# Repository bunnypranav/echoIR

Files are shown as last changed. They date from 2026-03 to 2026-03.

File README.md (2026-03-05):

# EchoIR


This is an IR hub, with both an IR receiver and a handful of transmitters, which can control my IR appliances, like the AC, fan, and TV, with my phone and over the internet. It wouldn't replace the remotes, but it could learn their signals and replay them whenever I want from my phone.

# Schematic
*Made in KiCad*

On the left side is the USB-C connector, going into the polyfuse, then into the +5V rail. The three IR LEDs each have their own 33-ohm resistor and connect from +5V to the IRLEDNODE. When the MOSFET turns on, current flows through all three LEDs to ground. The TSOP38238 receiver runs from +3.3V, which comes from the Pico's internal regulator. There is a 100nF capacitor and a 4.7uF capacitor close to it, because IR receivers are sensitive to noise. The button connected to GPIO 14 controls the "record" mode, with its status led just being the inbuilt Pi led at GPIO25.

page_1

# PCB
*Made in KiCad*
pcb
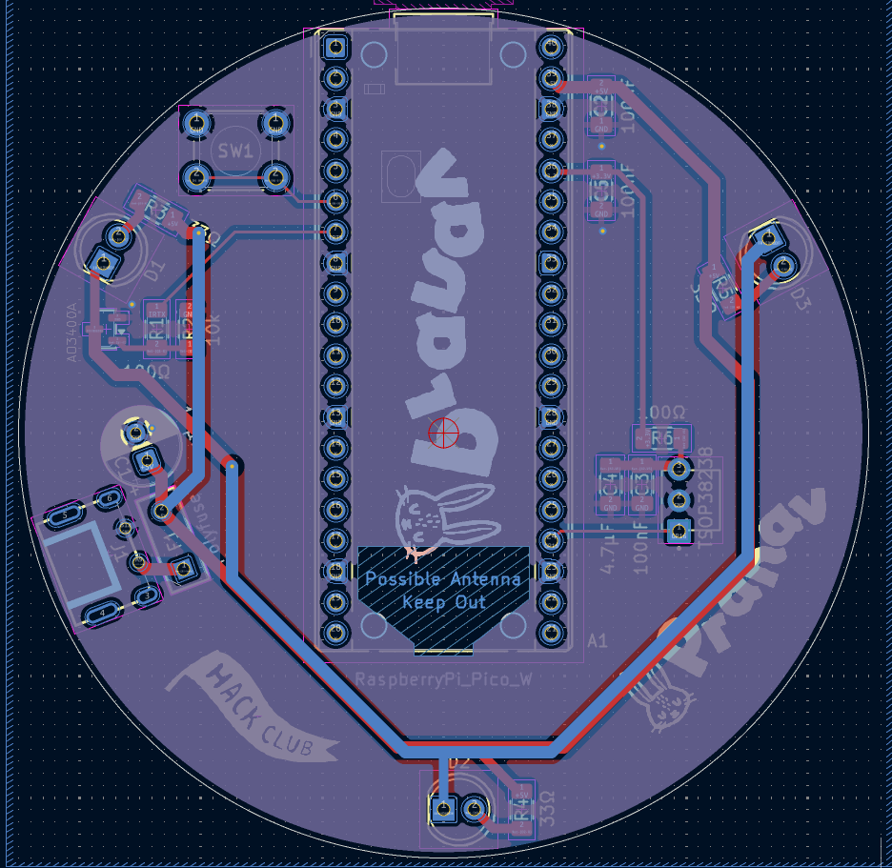
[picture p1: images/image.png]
pcb2


# Firmware
*Written in CircuitPython*

The Pico 2W connects to WiFi on boot and starts a HTTP server that exposes a simple webhook endpoint. When I press the button, it enters a short recording window and captures the raw pulse timings from the TSOP38238, then stores them in memory with an incrementing ID number. The IR LEDs are driven from GPIO5 using a 38kHz PWM carrier, and when a POST request is sent to `/play` with a JSON body like `{"id": 3}`, the Pico looks up that stored signal and replays it through the three IR transmitters. Everything runs locally on the Pico, so another computer on the same network can trigger appliances just by sending a simple HTTP request. This can also be easily plugged in to home automation services, or be modified to worth with MQTT, something I plan to do in the future.

# CAD Base
*Designed in Fusion 360*

Created a basic CAD base for the PCB to sit on. I did not create any top cover, since the LEDs cannot shine through solid PLA plastic, neither can the TSOP recieve IR pulses. This is just to prevent the bottom pins from scratching the surface I put this on.



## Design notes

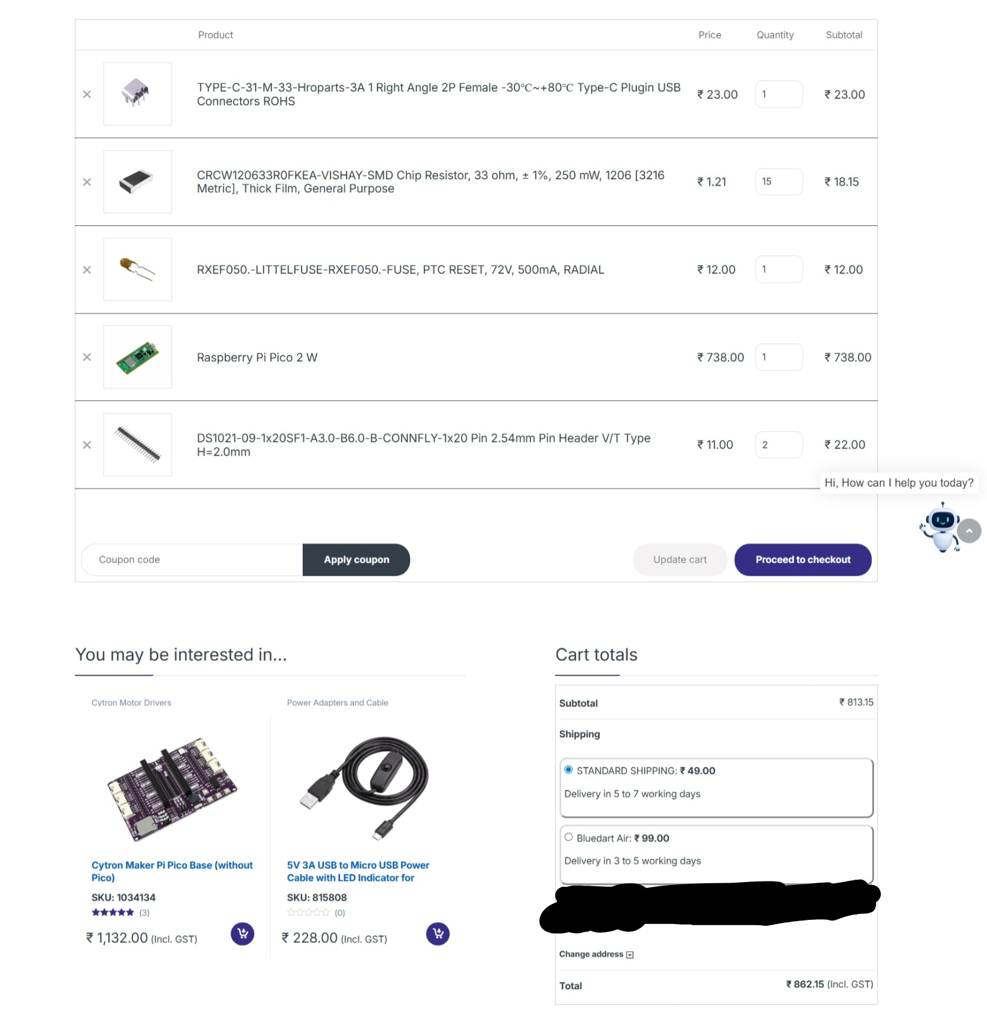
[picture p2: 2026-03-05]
CartScreenshots/Robu.png

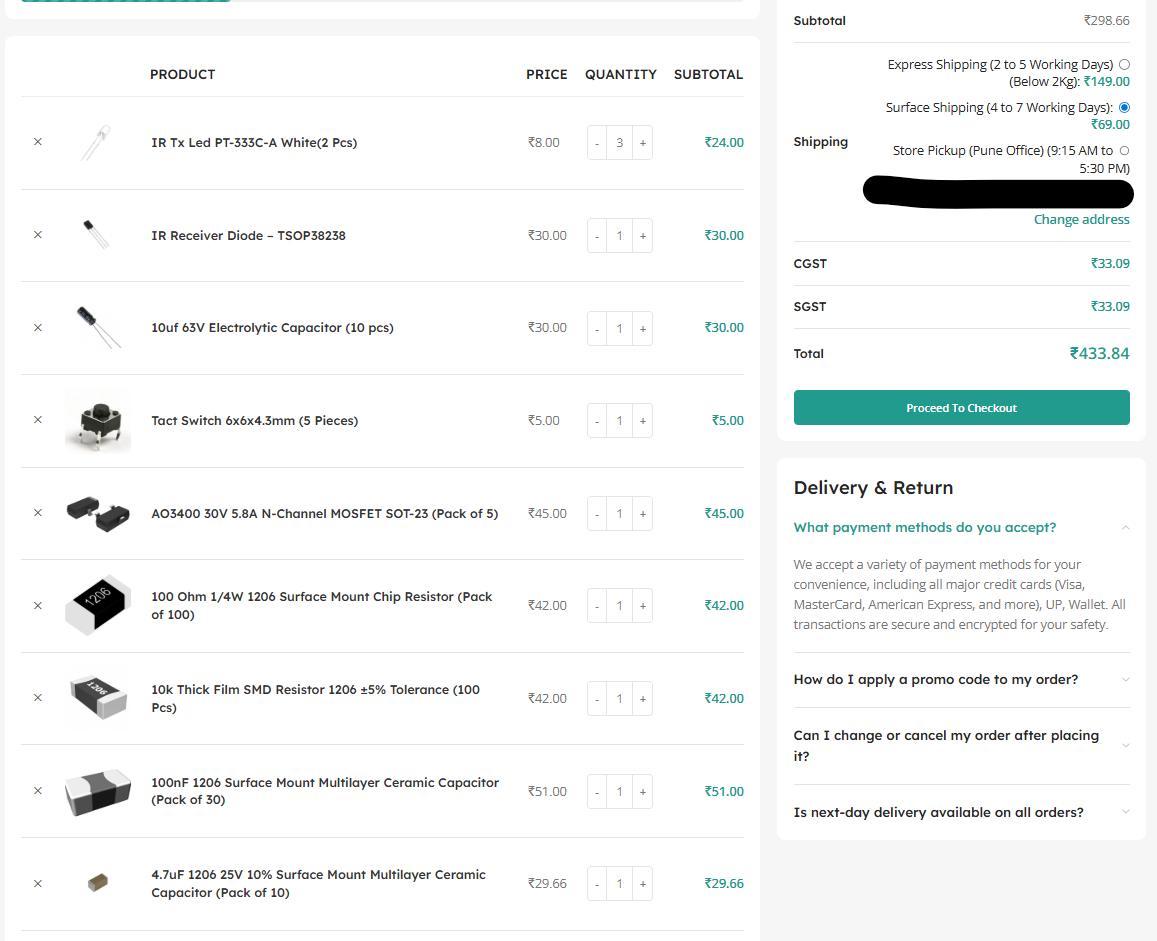
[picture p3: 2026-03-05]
CartScreenshots/robodna.png

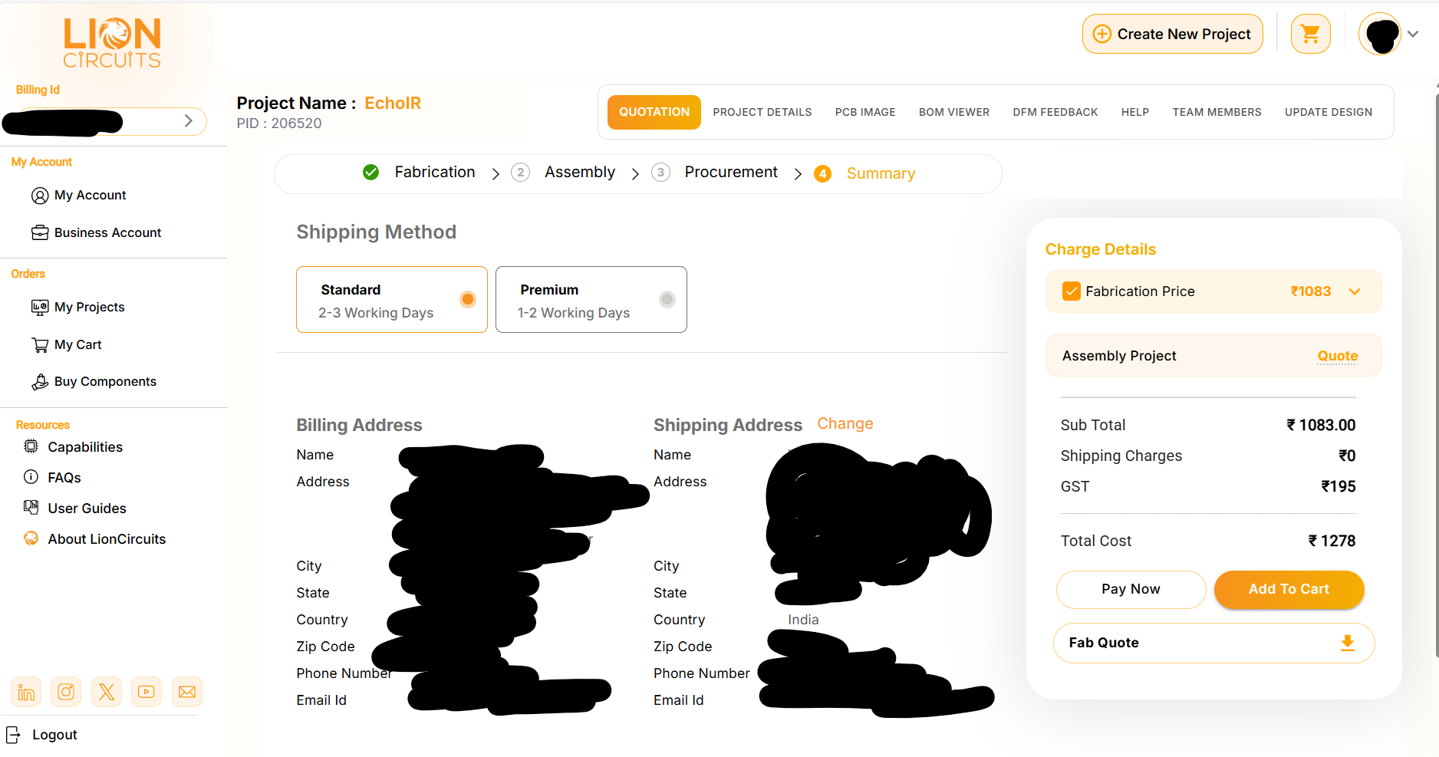
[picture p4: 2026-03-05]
CartScreenshots/PCB.png

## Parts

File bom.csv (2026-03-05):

Name | Purpose | Cost (USD) | Qty | Total (USD) | Link | Distributor
Printing legion shipping | Shipping cost for the 3D printed base from printing legion; domestic shipping within India | $3.00 | 1 | $3.00 | - | Shiprocket
33-ohm 1206 Resistor | LED resistor; 15 cause SMD is hard and I'm a beginner at soldering | $0.02 | 15 | $0.24 | https://robu.in/product/crcw120633r0fkea-vishay-smd-chip-resistor-33-ohm-%c2%b1-1-250-mw-1206-3216-metric-thick-film-general-purpose/ | Robu
LionCircuits PCB Fabrication | PCB Fabrication | $14.06 | 1 | $14.06 | https://lioncircuits.com/ | LionCircuits
RoboticsDNA Shipping | Standard cheapest shipping cost | $0.76 | 1 | $0.76 | - | RoboticsDNA
Robu Shipping | Standard cheapest shipping cost | $0.55 | 1 | $0.55 | - | Robu
Tactile Switch 6mm | Controlling mode | $0.07 | 1 | $0.07 | https://roboticsdna.in/product/tact-switch-2-pieces/ | RoboticsDNA
10k 1206 Resistor | MOSFET resistor | $0.55 | 1 | $0.55 | https://roboticsdna.in/product/10k%cf%89-thick-film-smd-resistor-1206-%c2%b15-tolerence-100-pcs/ | RoboticsDNA
100-ohm 1206 Resistor | LED power resistor | $0.55 | 1 | $0.55 | https://roboticsdna.in/product/100-ohm-1-4w-1206-surface-mount-chip-resistor-pack-of-100/ | RoboticsDNA
AO3400A | MOSFET | $0.59 | 1 | $0.59 | https://roboticsdna.in/product/ao3400-30v-5-8a-n-channel-mosfet-sot-23-pack-of-5/ | RoboticsDNA
USB C receptacle 31-M-33 | USB power | $0.26 | 1 | $0.26 | https://robu.in/product/type-c-31-m-33-hroparts-3a-1-right-angle-2p-female-30%e2%84%8380%e2%84%83-type-c-plugin-usb-connectors-rohs/ | Robu
RXEF050 Polyfuse | Fuse | $0.13 | 1 | $0.13 | https://robu.in/product/rxef050-littelfuse-rxef050-fuse-ptc-reset-72v-500ma-radial/ | Robu
IR Tx Led PT-333C-A | IR Transmission | $0.10 | 3 | $0.30 | https://roboticsdna.in/product/ir-tx-led-pt-333c-a-white2-pcs/ | RoboticsDNA
10uF radial Capacitor | Decoupling | $0.39 | 1 | $0.39 | https://roboticsdna.in/product/10uf-63v-capacitor-5-pieces/ | RoboticsDNA
TSOP38238 | IR reciever for training MCU | $0.39 | 1 | $0.39 | https://roboticsdna.in/product/ir-receiver-diode-tsop38238/ | RoboticsDNA
4.7uF 1206 Capacitor | Decoupling | $0.39 | 1 | $0.39 | https://roboticsdna.in/product/4-7uf-1206-surface-mount-multilayer-ceramic-capacitor-pack-of-30/ | RoboticsDNA
100nF 1206 Capacitor | Decoupling | $0.66 | 1 | $0.66 | https://roboticsdna.in/product/100nf-1206-surface-mount-multilayer-ceramic-capacitor-pack-of-30/ | RoboticsDNA
1x20 headers for Pico | THT mounting Pi, I am beginner at soldering | $0.12 | 2 | $0.24 | https://robu.in/product/ds1021-09-1x20sf1-a3-0-b6-0-b-connfly-1x20-pin-2-54mm-pin-header-v-t-type-h2-0mm/ | Robu
RaspberryPi Pico 2 W | Main MCU and Wifi connectivity | $8.12 | 1 | $8.12 | https://robu.in/product/raspberry-pi-pico-2-w/ | Robu

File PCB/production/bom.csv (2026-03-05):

Designator | Footprint | Quantity | Value | LCSC Part #
A1 | RaspberryPi_Pico_Common_THT | 1 | RaspberryPi_Pico_W
A2 | XDCR_TSOP38238 | 1 | TSOP38238
C1 | CP_Radial_D6.3mm_P2.50mm | 1 | 10µF
C2, C3, C5 | 1206 | 3 | 100nF
C4 | 1206 | 1 | 4.7µF
D1, D2, D3 | LED_D5.0mm | 3 | LED
F1 | FUS_RXEF050_TYCO_TYC | 1 | Polyfuse
J1 | USB-C-TH_TYPE-C-31-M-33 | 1 | USB_C_Receptacle_PowerOnly_6P
Q1 | SOT-23 | 1 | AO3400A
R1, R6 | 1206 | 2 | 100Ω
R2 | 1206 | 1 | 10k
R3, R4, R5 | 1206 | 3 | 33Ω
SW1 | SW_PUSH_6mm | 1 | SW_Push

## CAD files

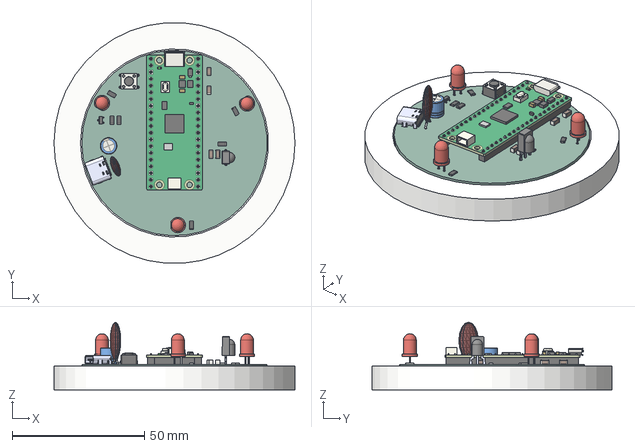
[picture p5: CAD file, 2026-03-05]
CAD/echoIR_fullProject.step
91.0 x 90.7 x 25.6 mm

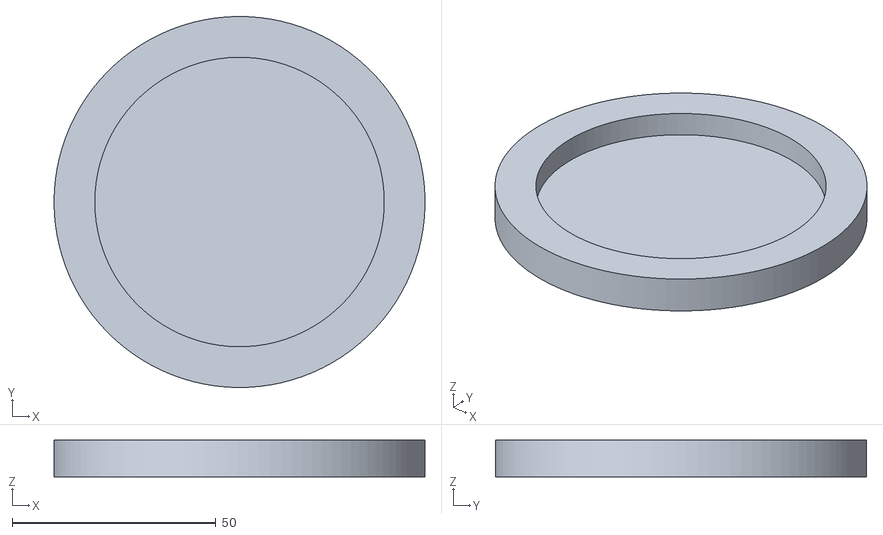
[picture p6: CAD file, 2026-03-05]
CAD/Base.stl
91.0 x 91.0 x 9.00

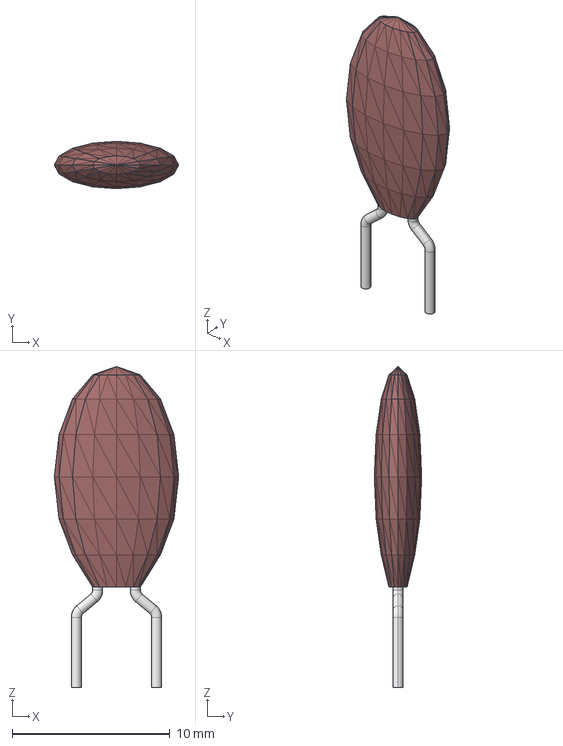
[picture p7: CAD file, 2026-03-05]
PCB/SymbolFootprints/RXEF050/FUS_RXEF050_TYCO_TYC.step
7.87 x 3.00 x 20.3 mm

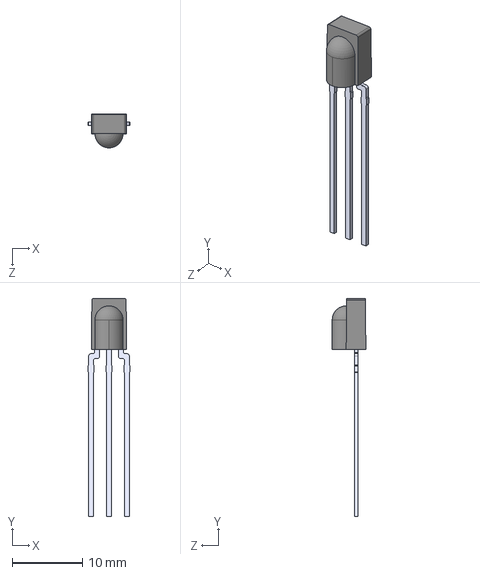
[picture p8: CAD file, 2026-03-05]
PCB/SymbolFootprints/TSOP38238/TSOP38238.STEP
5.93 x 31.0 x 4.80 mm

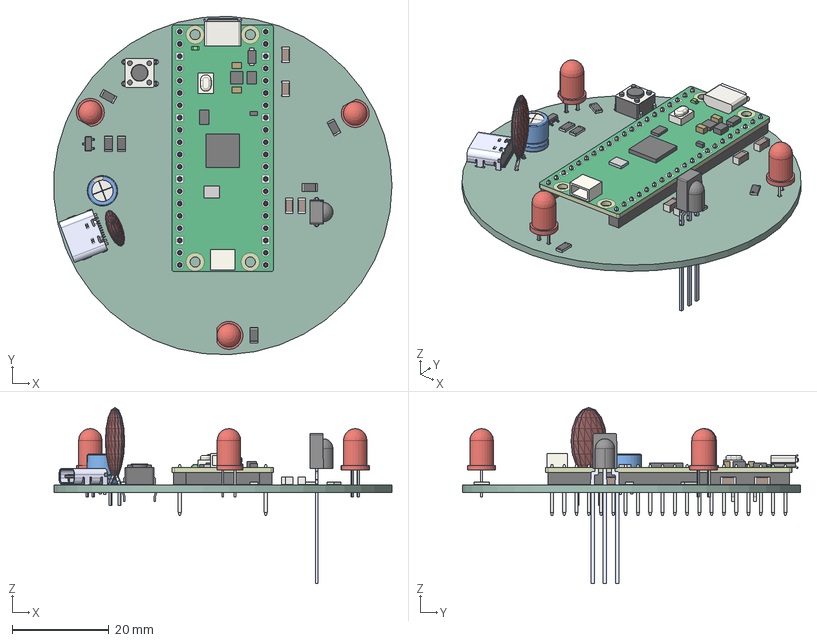
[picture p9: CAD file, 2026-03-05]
CAD/PCB.step
69.9 x 69.9 x 36.4 mm
LED_D5.0mm x 3
C_1206_3216Metric x 4
R_1206_3216Metric x 6
SOT-23
TYPE-C-31-M-12
TSOP38238
RaspberryPi_Pico_H_Module_KiCad
RaspberryPi_Pico_Header_DIP-40_H2.54mm_KiCad
CP_Radial_D6.3mm_P2.50mm
SW_PUSH_6mm
FUS_RXEF050_TYCO_TYC
echoIR_PCB

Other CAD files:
CAD/echoIR_fullProject.f3z

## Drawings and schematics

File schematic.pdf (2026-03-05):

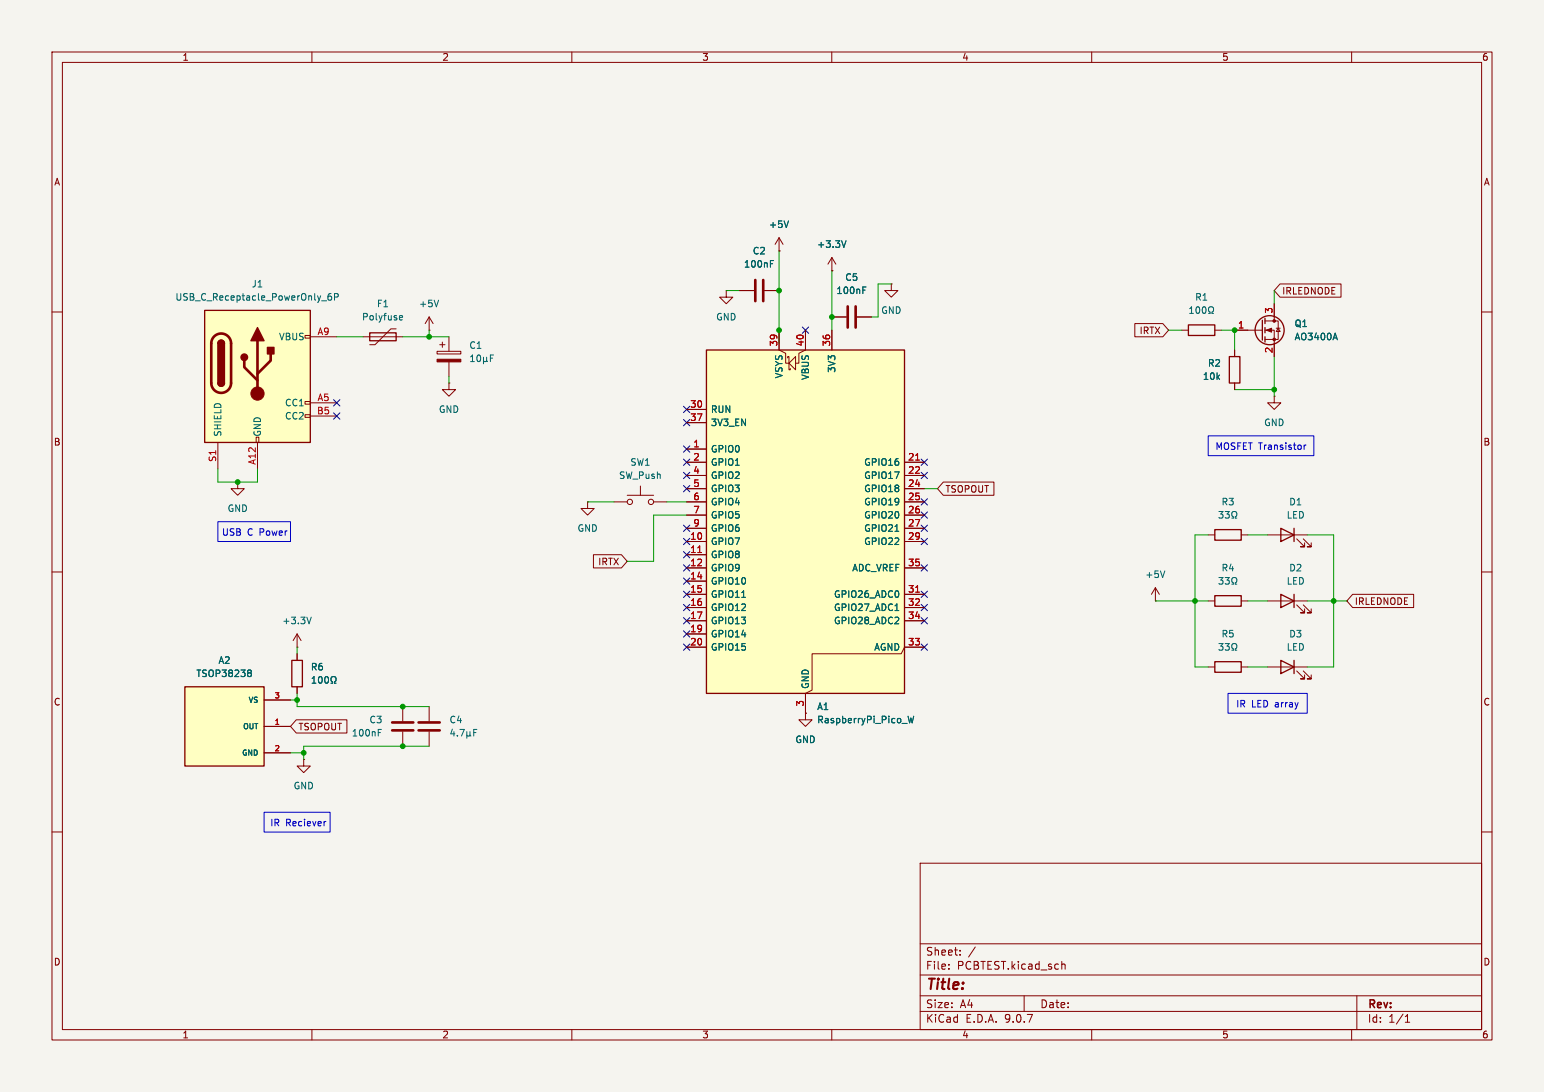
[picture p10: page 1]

IR LED array MOSFET Transistor A2 TSOP38238

Id: 1/1 Title: File: PCBTEST.kicad_sch Sheet: /

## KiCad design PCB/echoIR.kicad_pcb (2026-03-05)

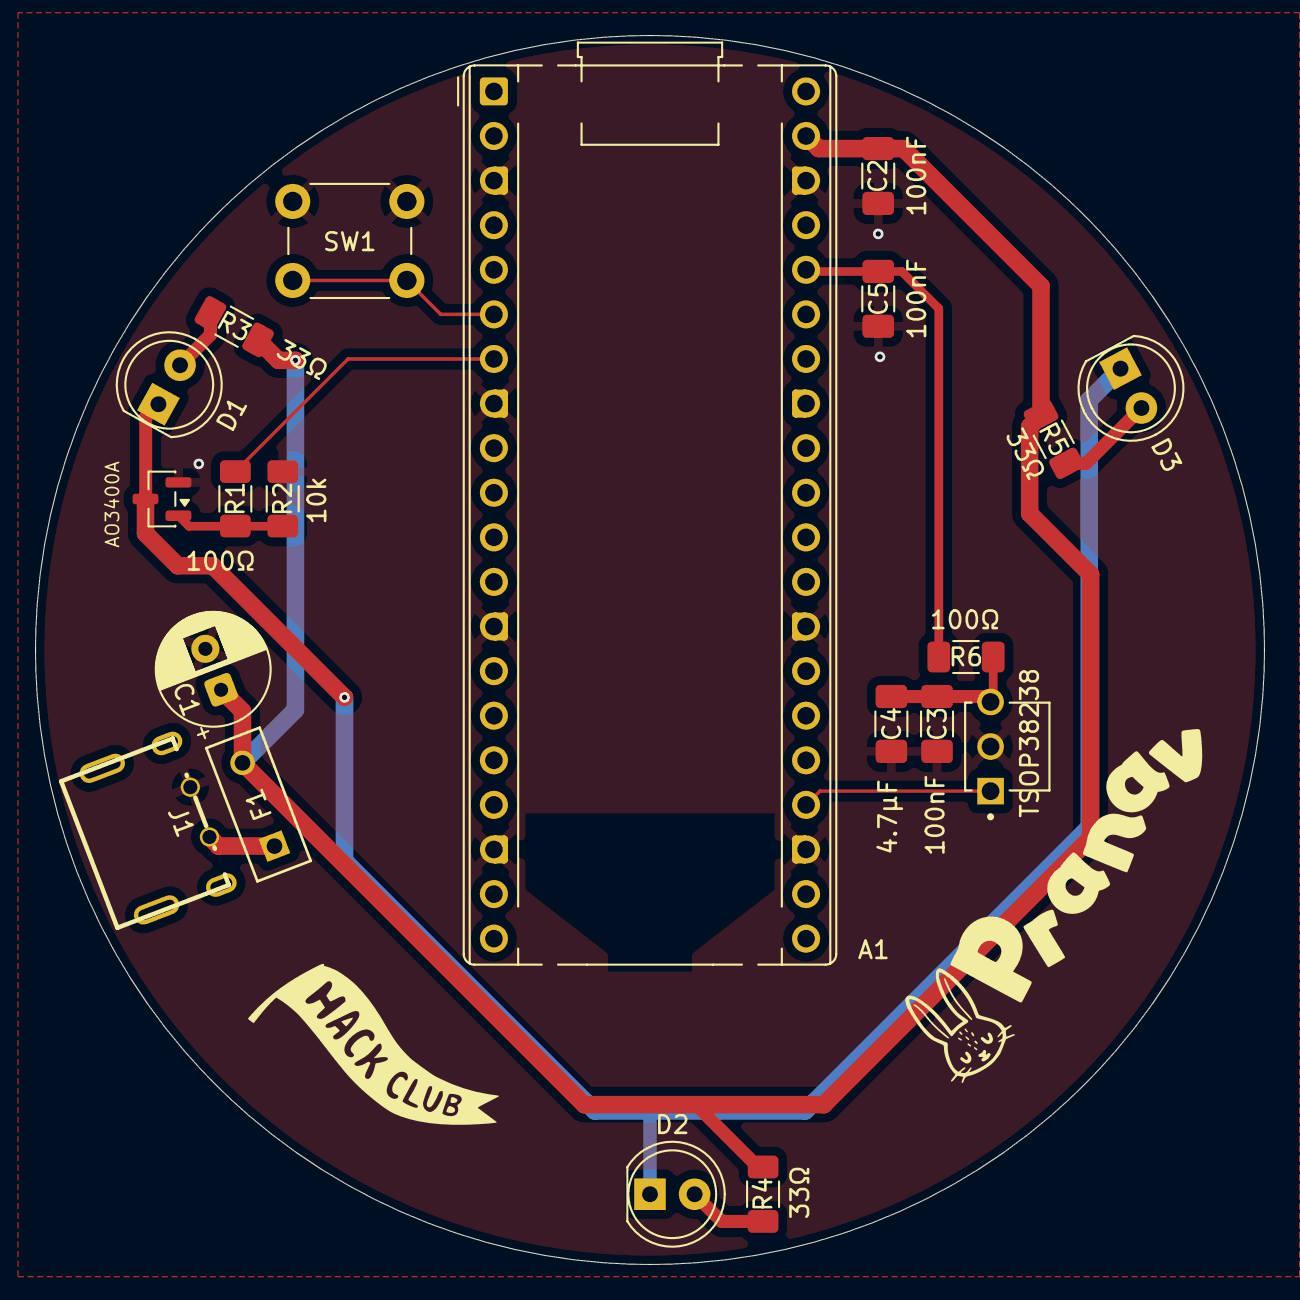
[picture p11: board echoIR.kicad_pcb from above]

Board: 2 copper layers, 70.0 x 70.0 mm, 20 parts (0 on the bottom side), 13 nets.

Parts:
A1: RaspberryPi_Pico_W; RaspberryPi_Pico_Common_THT
A2: TSOP38238; XDCR_TSOP38238
C1: 10µF; CP_Radial_D6.3mm_P2.50mm
C2, C3, C5: 100nF; C_1206_3216Metric_Pad1.33x1.80mm_HandSolder
C4: 4.7µF; C_1206_3216Metric_Pad1.33x1.80mm_HandSolder
D1, D2, D3: LED; LED_D5.0mm
F1: Polyfuse; FUS_RXEF050_TYCO_TYC
J1: USB_C_Receptacle_PowerOnly_6P; USB-C-TH_TYPE-C-31-M-33
Q1: AO3400A; SOT-23
R1, R6: 100Ω; R_1206_3216Metric_Pad1.30x1.75mm_HandSolder
R2: 10k; R_1206_3216Metric_Pad1.30x1.75mm_HandSolder
R3, R4, R5: 33Ω; R_1206_3216Metric_Pad1.30x1.75mm_HandSolder
SW1: SW_Push; SW_PUSH_6mm

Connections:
+3.3V: A1.36 (3V3), C5.1, R6.2
+5V: A1.39 (VSYS), C1.1, C2.2, F1.2, R3.1, R4.1, R5.1
GND: A1.3 (GND), A1.8 (GND), A1.13 (GND), A1.18 (GND), A1.23 (GND), A1.28 (GND), A1.38 (GND), A2.2 (GND), C1.2, C2.1, C3.2, C4.2, C5.2, J1.B12 (GND), Q1.2 (S), R2.2, SW1.1
GP16: A1.24 (GPIO18), A2.1 (OUT)
IRLEDNODE: D1.1 (K), D2.1 (K), D3.1 (K), Q1.3 (D)
IRTX: A1.7 (GPIO5), R1.1
unnamed: A1.6 (GPIO4), SW1.2
unnamed: A2.3 (VS), C3.1, C4.1, R6.1
unnamed: D1.2 (A), R3.2
unnamed: D2.2 (A), R4.2
unnamed: D3.2 (A), R5.2
unnamed: F1.1, J1.A9 (VBUS)
unnamed: Q1.1 (G), R1.2, R2.1

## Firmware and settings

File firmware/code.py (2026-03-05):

import board
import digitalio
import pwmio
import time
import json
import microcontroller
import wifi
import socketpool
import adafruit_httpserver
from adafruit_httpserver import Server, Request, Response
from adafruit_httpserver.mime_type import MIMEType
from secrets import secrets

# Pins
IRTXPIN = board.GP5
IRRXPIN = board.GP18
BUTTONPIN = board.GP4

# IR transmitter
ir_pwm = pwmio.PWMOut(IRTXPIN, frequency=38000, duty_cycle=0)


def carrier_on():
    ir_pwm.duty_cycle = 32768


def carrier_off():
    ir_pwm.duty_cycle = 0


# IR receiver
ir_rx = digitalio.DigitalInOut(IRRXPIN)
ir_rx.direction = digitalio.Direction.INPUT

# Button
button = digitalio.DigitalInOut(BUTTONPIN)
button.direction = digitalio.Direction.INPUT
button.pull = digitalio.Pull.UP

# Signal Storage
ir_signals = {}
next_signal_id = 1


def sleep_us_precise(duration_us):
    if duration_us <= 0:
        return

    if duration_us > 2500:
        time.sleep((duration_us - 500) / 1_000_000)

    target = time.monotonic_ns() + (duration_us * 1000)
    while time.monotonic_ns() < target:
        pass


# Recording
def record_ir(duration=3):
    global next_signal_id

    print("Recording IR")
    start_time = time.monotonic()
    last_state = ir_rx.value
    segments = []
    last_change = time.monotonic_ns()

    while time.monotonic() - start_time < duration:
        current_state = ir_rx.value
        if current_state != last_state:
            now = time.monotonic_ns()
            delta = (now - last_change) // 1000
            segments.append((last_state, delta))
            last_change = now
            last_state = current_state

    now = time.monotonic_ns()
    delta = (now - last_change) // 1000
    if delta > 0:
        segments.append((last_state, delta))

    signal_id = next_signal_id
    ir_signals[signal_id] = segments
    next_signal_id += 1

    print("Saved as ID:", signal_id)
    return signal_id


# Replay
def replay_ir(signal_id):
    if signal_id not in ir_signals:
        print("Invalid ID")
        return

    print("Replaying ID:", signal_id)
    segments = ir_signals[signal_id]

    for level, duration_us in segments:
        if not level:
            carrier_on()
        else:
            carrier_off()
        sleep_us_precise(duration_us)

    carrier_off()
    print("Done")


# WiFi setup
print("Connecting to WiFi...")
wifi.radio.connect(secrets["ssid"], secrets["password"])
print("Connected:", wifi.radio.ipv4_address)

pool = socketpool.SocketPool(wifi.radio)
server = Server(pool, "/static")


# Webhook Endpoint
@server.route("/play", methods=["POST"])
def play_handler(request: Request):
    try:
        data = request.json()
        signal_id = int(data["id"])
        replay_ir(signal_id)
        return Response(request, "Played", MIMEType.TEXT)
    except Exception as e:
        return Response(request, "Error: " + str(e), MIMEType.TEXT)


server.start(str(wifi.radio.ipv4_address))

print("Webhook ready at:")
print("http://" + str(wifi.radio.ipv4_address) + "/play")

# Main Loop
last_button_state = True

while True:
    server.poll()

    current_button_state = button.value

    if not current_button_state and last_button_state:
        time.sleep(0.2)
        if not button.value:
            record_ir()

    last_button_state = current_button_state
